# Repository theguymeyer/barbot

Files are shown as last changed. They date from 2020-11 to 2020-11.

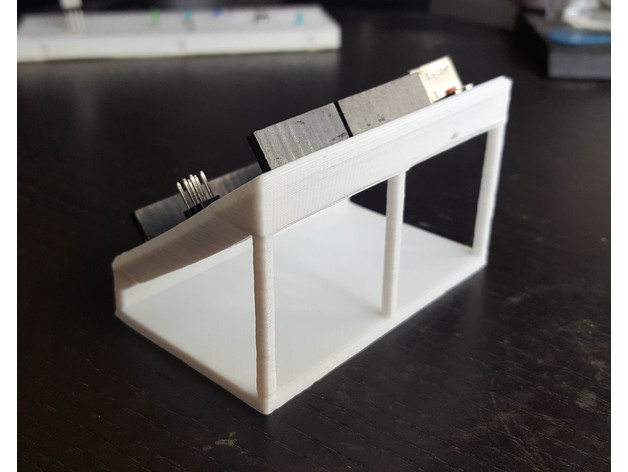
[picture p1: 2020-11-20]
CAD/Arduino_Uno_Breadboard_Stand/images/e8f078489b42e7dd9708c227b31c532c_preview_featured.jpg

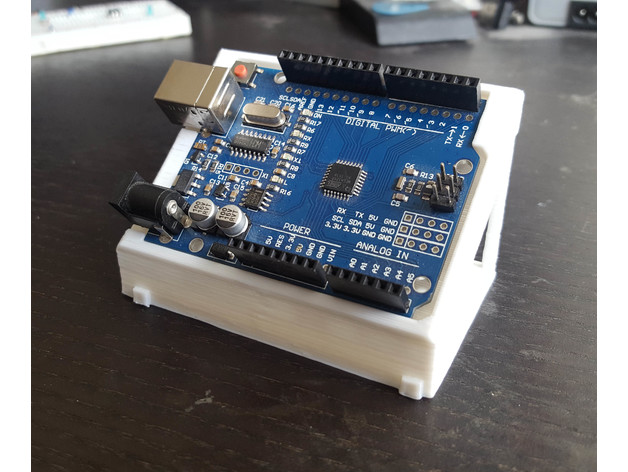
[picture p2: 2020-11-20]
CAD/Arduino_Uno_Breadboard_Stand/images/93188645c2328523fab258e460d34e7b_preview_featured.jpg

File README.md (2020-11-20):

# Bartender Robot

Feelin thirsty? Why dont you spend every summer obsessing over the same project until you get it perfectly... Introducing the Barbot, an autonomous bartender that won't charge you double for a watered down beverage.

But... how? Well this beauty is built on top the finest shelf Ikea has to offer, along with a custom bottle mount this bad boy can hold up to 5 bottles in a line. The main controller (mainFile_rev1) is an Arduino Uno that controls a Bipolar NEMA 17 to move the cup and a set of relays to power the solenoid valve the pneumatics. In order to get enough juice on the pouring action (something that for the life of me, I did not imagine would be so hard) is a 2-stroke pneumatic piston operating under 45 PSI of pressure, controlled by a 2-position 12V Solenoid Valve. The air channels are also equipt with a tunable flow restrictor to provide smooooooooth motion.

Well thats cool but how do I use it? The UI is displayed on an LCD mounted on top another Arduino Uno (yes... the budget was low). The user can scroll between the drink options, select their favourite and watch the bartender go to work.

Just like most of my excessively detailed projects, there are a total of 17 3D printed parts plus other custom elements!

If you enjoyed checking out this project take a look at [my project page](https://guymeyer.me/projects)

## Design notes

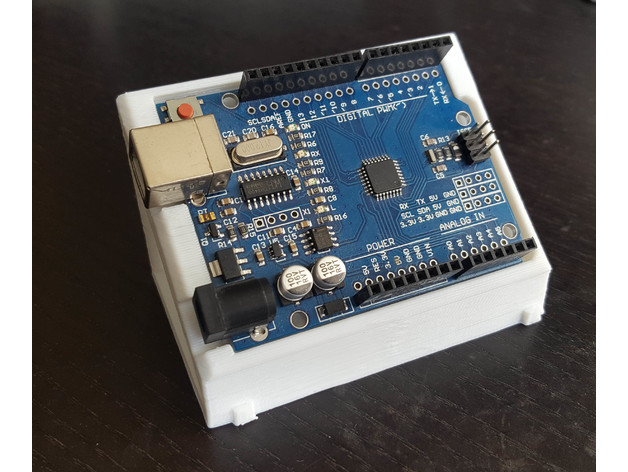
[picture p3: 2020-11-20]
CAD/Arduino_Uno_Breadboard_Stand/images/13b41aad88eadf36f711034ac9c3a466_preview_featured.jpg

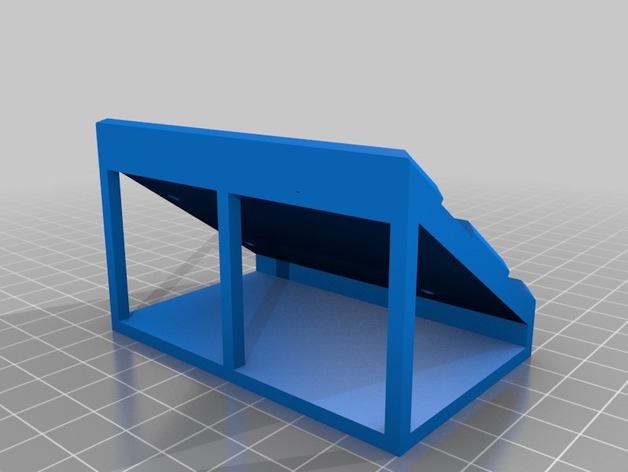
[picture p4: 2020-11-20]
CAD/Arduino_Uno_Breadboard_Stand/images/f9ae25f701ae45b652f5ff1a13d86fba_preview_featured.jpg

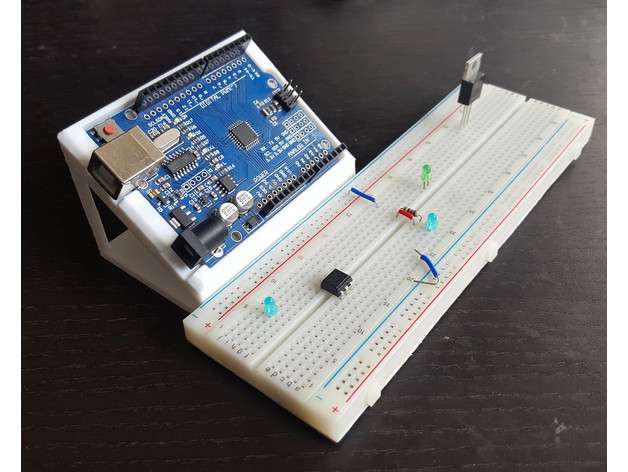
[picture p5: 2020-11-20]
CAD/Arduino_Uno_Breadboard_Stand/images/585fe109f0ed7a9347ead8bb23d2d4b8_preview_featured.jpg

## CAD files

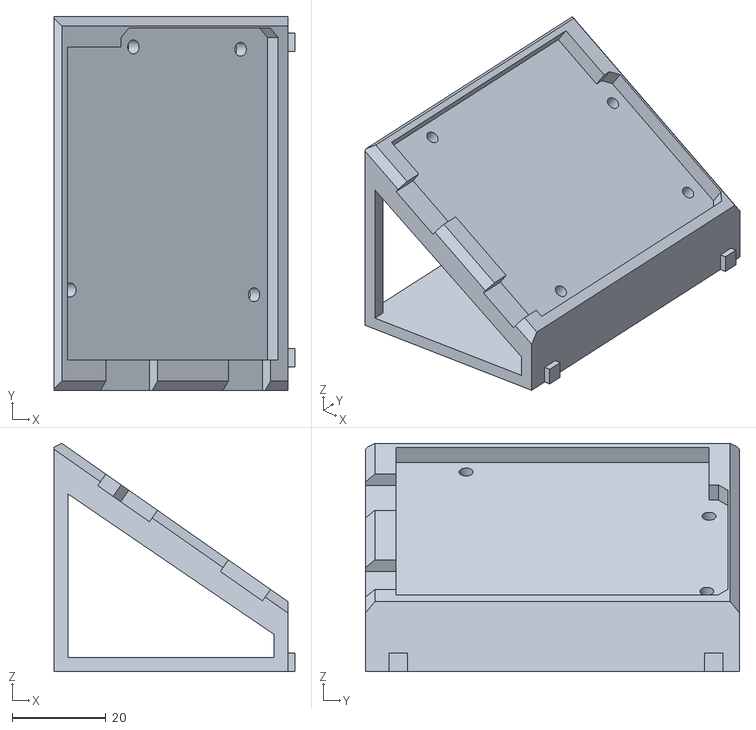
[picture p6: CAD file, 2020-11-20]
CAD/Arduino_Uno_Breadboard_Stand/files/ArduinoUno_Stand.stl
51.5 x 80.0 x 48.9

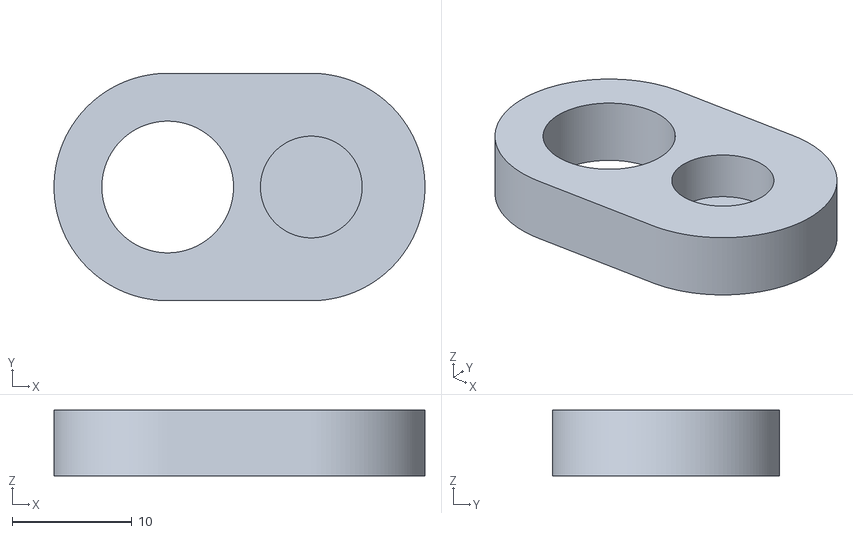
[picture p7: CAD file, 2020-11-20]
CAD/magnet_holder_piston.stl
31.0 x 19.0 x 5.50

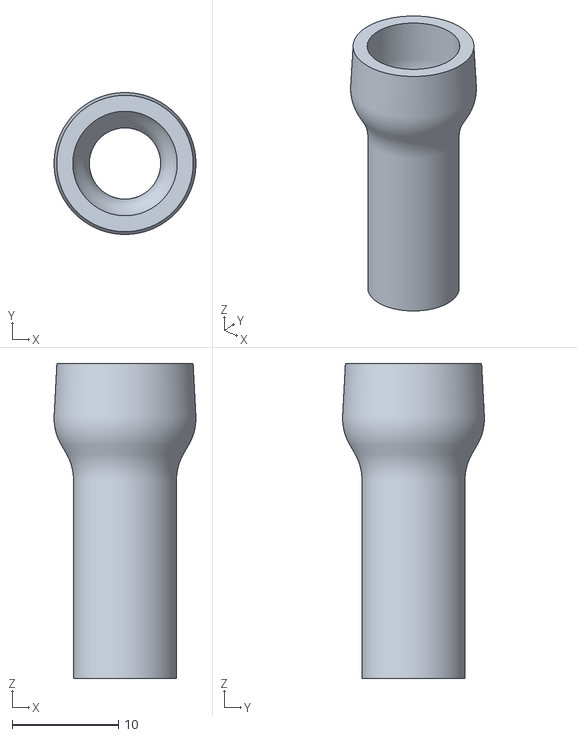
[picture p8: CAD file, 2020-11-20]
CAD/bottle_valve_coupler.stl
13.4 x 13.4 x 29.7

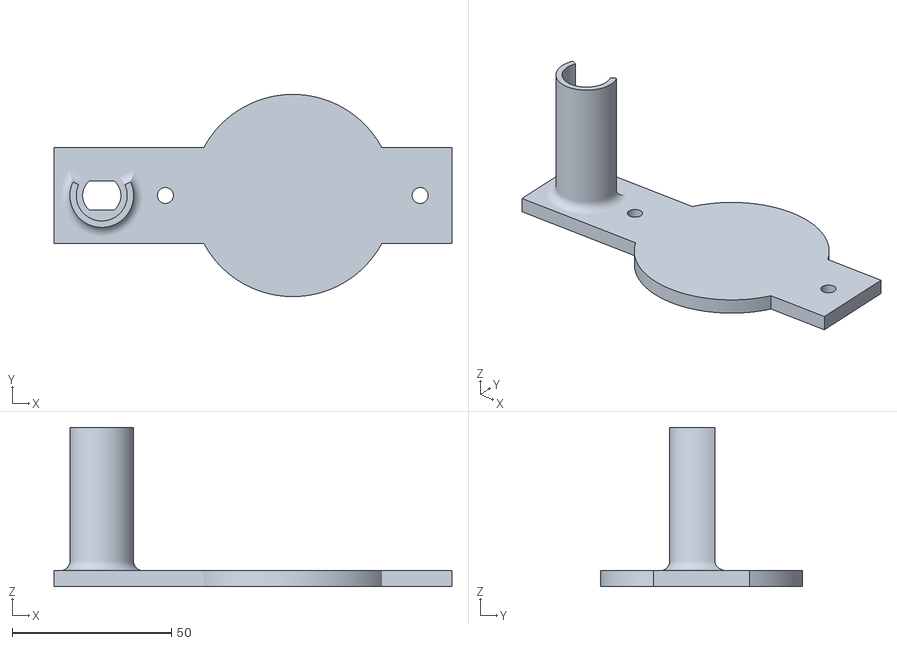
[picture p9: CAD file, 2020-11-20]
CAD/drink_machine_cup_holder.stl
125.0 x 63.5 x 50.0

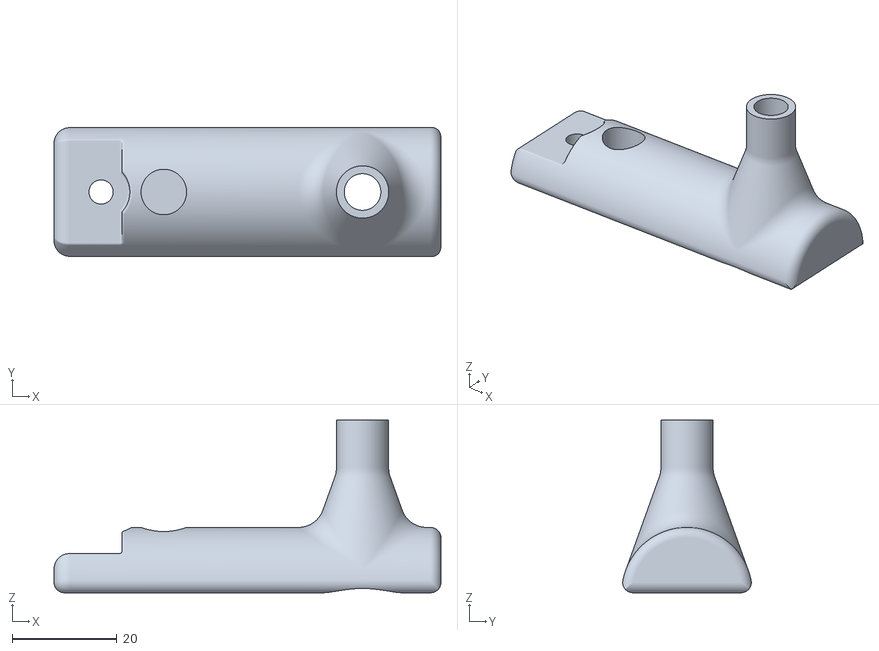
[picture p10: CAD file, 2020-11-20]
CAD/drink_machine_piston_manipulator_rev4.stl
74.0 x 24.6 x 33.0

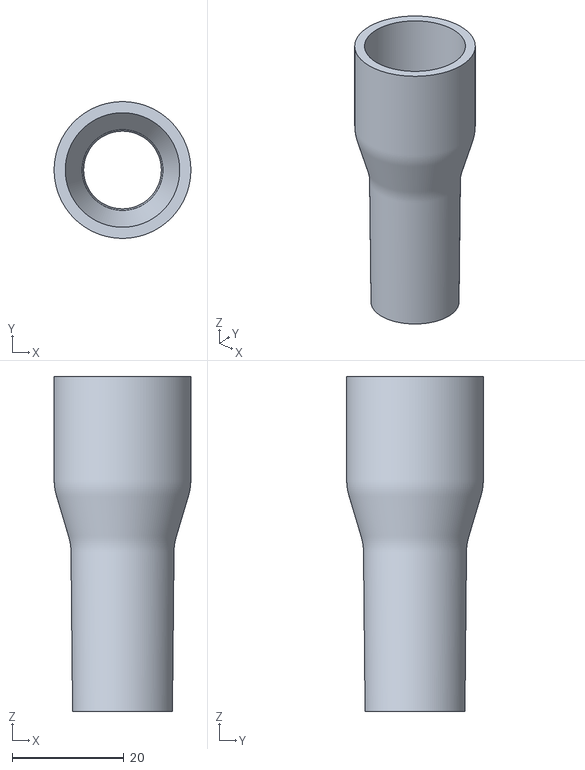
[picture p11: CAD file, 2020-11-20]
CAD/bottle_valve_coupler2.stl
24.5 x 24.5 x 60.0

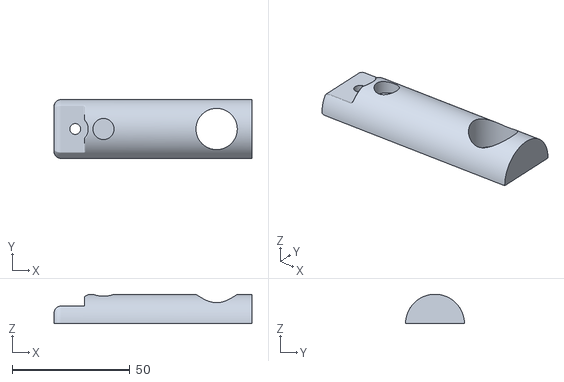
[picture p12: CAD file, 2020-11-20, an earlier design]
CAD/drink_machine_piston_manipulator_rev1.stl
84.0 x 25.0 x 12.5

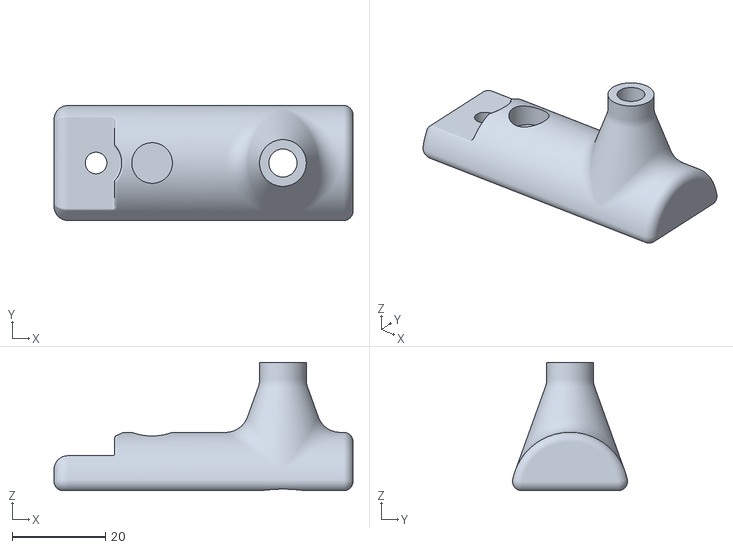
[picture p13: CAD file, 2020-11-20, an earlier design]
CAD/drink_machine_piston_manipulator_rev3.stl
64.0 x 24.6 x 27.5

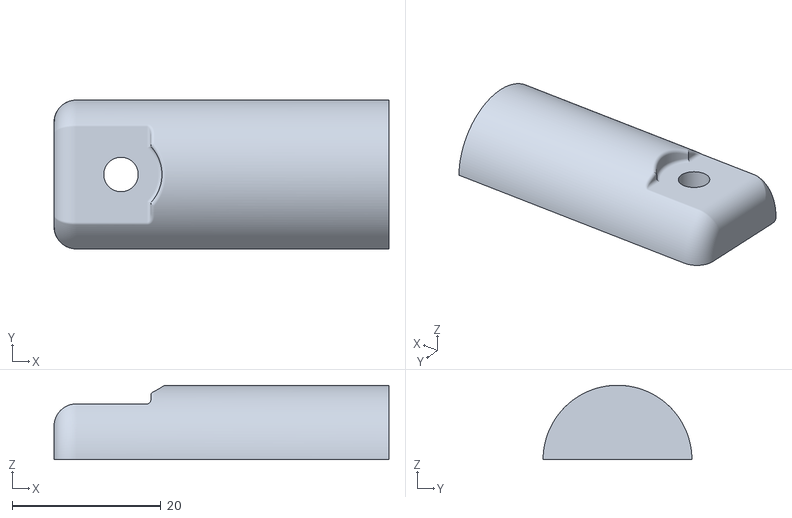
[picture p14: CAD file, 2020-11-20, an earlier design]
CAD/drink_machine_piston_manipulator_rev0.stl
45.0 x 20.0 x 10.0

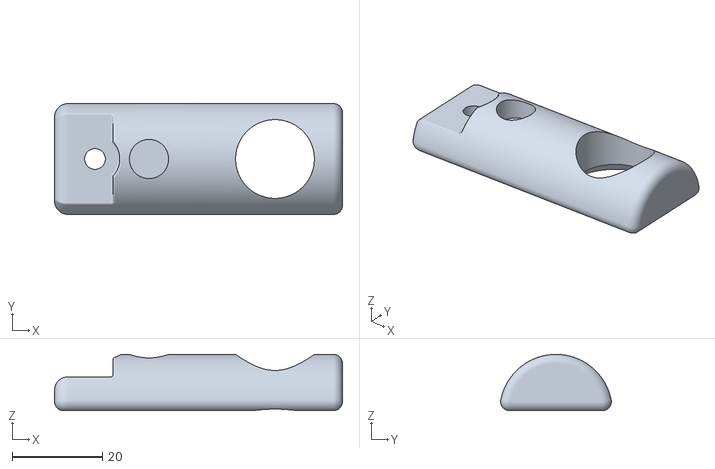
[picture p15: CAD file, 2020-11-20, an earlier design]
CAD/drink_machine_piston_manipulator_rev2.stl
64.0 x 24.6 x 12.5

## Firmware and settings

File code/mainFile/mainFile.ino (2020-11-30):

// Author: Guy Meyer
// Date of creation: May 18th 2020
// Last change date: June 8th 2020
// Objective: accept user input (serial) and execute the drink combination
// System Description:
//	- Hardware: 
//      IR Sensor
//      200 step NEMA 17 Bipolar Stepper providing linear motion underneat bottles
//      12VDC Pneumatic Valve + 2-way piston used to dispense drink + 200 PSI compressor (set to 40 PSI)
//
//	- Electrical: 
//      9VDC stable power. 
//      The RESET button is electrically connected to the power of the board and will perform a hard reset (ie. reinitialization).
//      IR senses proximity and outputs 5V bollean value
//
//	- Software: 
//			INPUT: a serial message indicating the drink requirements based on 5 unique bottle
//			serial message structure: uint8{Bottle_1, Bottle_2, Bottle_3, Bottle_4, Bottle_5} @ BAUDRATE=9600 via RX/TX serial bus
//			where each Bottle is a byte describing the number of shots from each bottle in ASCII. The system is not concerned with speed optimization with the serial buffer
//
//      OUTPUT: 
//      Electrical signals to stepper based on Bottle. 
//      Stops stepper if reached endpoint
//      Toggles solenoid via electrical signals
//      System timing
//      Serial reply when completed
//      `
//
// Design: 
//      On init -> INIT state 
//        - the system will write init_code to serial buffer indicating that its ready to serve
//        - the system will reset its end-effector -> first move piston down, then reset rail to starting position
//      USER_INPUT state
//        - detected new message in serial buffer
//        - Parse serial message to build drink list
//      PATH_PLANNER state
//        - Build a plan for the stepper's motion
//      MAKE_DRINK state
//        LOOP: move to bottle -> pour shot (x number of shots) -> if more bottle repeat, else break
//      SERVE_DRINK state
//        - the system will reset its end-effector -> first move piston down, then reset rail to starting position
//        - the system will send finished drink code to UI
//
//         /                                     /                                  /
//      _\/_______                            _\/__________                      _\/____________                   _______________                   _______________  
//  o-->|  INIT   |          -->              | USER_INPUT |       -->           | PATH_PLANNER |       -->        |  MAKE_DRINK  |       -->        | SERVE_DRINK |
//      |_________|  SERIAL INIT DETECTED     |____________|   PARSED MESSAGE    |______________|  DEFINED PLAN    |______________|  EXECUTED PATH   |_____________|
//                                                /\                                                                                                       |
//                                                 |_______________________________________________________________________________________________________|
//                                                                                                SERIAL DETECTED (new drink)
//
//
//

#include <Adafruit_MotorShield.h>
#include <Vector.h>

#define DRINK_COUNT 5
#define IR_THRESHOLD 0.9

#define BOTTLE1_POS 500   // in number fo steps from start
#define BOTTLE2_POS 1500
#define BOTTLE3_POS 2500
#define BOTTLE4_POS 3500
#define BOTTLE5_POS 4500
#define RAIL_MAX 5500

// TESTING
//#define BOTTLE1_POS 100   // in number fo steps from start
//#define BOTTLE2_POS 200
//#define BOTTLE3_POS 300
//#define BOTTLE4_POS 400
//#define BOTTLE5_POS 500
//#define RAIL_MAX 1000

#define DRINK_HOLD_TIME 3000
#define DRINK_INBETWEEN_TIME 2500

//using namespace std;

// init variables
int LimitSW_Pin = 2;    // connected to digital 2
int pistonUp_Pin = 6;   // pneumatic controls
int pistonDown_Pin = 7;
int bottle_position [5] = {BOTTLE1_POS, BOTTLE2_POS, BOTTLE3_POS, BOTTLE4_POS, BOTTLE5_POS};

Adafruit_MotorShield AFMS = Adafruit_MotorShield(); 
Adafruit_StepperMotor *myMotor = AFMS.getStepper(200, 1);


// state variables
int pmsg [DRINK_COUNT] = {0};  // parsed message
int path [DRINK_COUNT][2] = {0}; // servo path
int stop_count = 0;

/* --- Custom Functions --- */

// alters the solenoid values to move the piston DOWN
bool pistonDown()
{
  digitalWrite(pistonUp_Pin, LOW);
  digitalWrite(pistonDown_Pin, HIGH);
}

// alters the solenoid values to move the piston UP
bool pistonUp()
{
  digitalWrite(pistonDown_Pin, LOW);
  digitalWrite(pistonUp_Pin, HIGH);
}

// moves the drink closer to the IR (starting position) with incremental steps
// -> return true on successful motion (returns false otherwise)
bool resetRail()
{
  pistonDown(); 
  delay(2000);
  
  while(!(isStepperAtStart())) {
    myMotor->step(10, FORWARD, DOUBLE);  // move closer
    delay(2); // give the motor time to move
  }

  // reached start
  pistonUp();
  return true;

}

bool isStepperAtStart()
{
  
  if (digitalRead(LimitSW_Pin)) {
    return true;
  }

  return false;
}

/* --- State Functions (executed on entry unless otherwise noted) --- */

// system init - runs on boot
// -> returns true when serial is established and the rail is reset (returns false otherwise)
bool init_sys()
{

  String ACK;
  if (Serial.available()) {
    ACK = Serial.readString();  // ACK receive

    if (ACK == "OK\n") {  // transition criteria

      resetRail();

      Serial.flush();
      Serial.flush();
      return true;
    }
  }

  return false;

}

// a waiting state for serial input regarding drink info
// updates the message buffer from serial stream (requirements for each drink) starting from closest
void userInput(int msg_buffer[])
{

  String message = Serial.readString();

  if (message != NULL) {  // if message in buffer
    for (int i = 0; i < DRINK_COUNT; i++) {
      msg_buffer[i] = message[i] - '0';
    }
  }

  // clean up
  Serial.flush();
  Serial.flush();

}

// Takes the user input and builds a path for the servo as a list of steps with directions
// returns a list of instructions for the stepper (2d vector) [direction, steps, shots]
// direction defined as 0 - FORWARD (closer to start), 1 - BACKWARD (away from start) 
// RETURNS the number of stops (ie. number of different requested drinks, the volume of each does not matter)
int pathPlanner(int msg_buffer[], int path_buffer[][2])
{
  // Note this function can be later optimized for better path planning
  
//  while (!isStepperAtStart()) { resetRail(); }

  int instruction [2] = {0,0};
  int path_index = 0;
  for (int d = 0; d < DRINK_COUNT; d++) {

    if (msg_buffer[d] != 0) {
      path_buffer[path_index][0] = bottle_position[d];
      path_buffer[path_index][1] = msg_buffer[d];
      path_index ++;
    }

  }

  return path_index;

}

// Execution of path - moves cup through positions and pours liquor
// Assumption: only requested liquors are in the path buffer
void exec(int path_buf[][2], int stop_count)
{

  resetRail();
  pistonDown();
  delay(1000);

  int loc = 50;
  uint8_t dir;
  
  myMotor->step(loc, BACKWARD, DOUBLE);

  for (int i = 0; i < stop_count; i++) {

    // move stepper to position until within margin of error - 10 steps
    while (abs(path_buf[i][0] - loc) > 1) {
      
      if (isStepperAtStart() || loc > RAIL_MAX) { 
        pistonDown();
        resetRail();
        return ; 
      }
      
      if (path_buf[i][0] > loc) {
        myMotor->step(1, BACKWARD, DOUBLE);
        loc++;
      } else {
        myMotor->step(1, FORWARD, DOUBLE);
        loc--;
      }

//      delay(2); // give the motor time to move
    }

    for (int j = 0; j < path_buf[i][1]; j++) {

      delay(DRINK_INBETWEEN_TIME);
      pistonUp();
      delay(DRINK_HOLD_TIME);
      pistonDown();
      delay(DRINK_INBETWEEN_TIME);

    }

    
    delay(300);

  }

  // return home
  resetRail();
  delay(100);
  myMotor->release();
  
}

void setup() 
{ 
  Serial.begin(9600); // init serial - no direct imports

  while (!Serial)
  {
    ; // wait for serial port to connect. Needed for native USB port only
  }

  AFMS.begin();  // create with the default frequency 1.6KHz
  myMotor->setSpeed(1000);  // 10 rpm 
  
  pinMode(LimitSW_Pin, INPUT);
  pinMode(pistonUp_Pin, OUTPUT);
  pinMode(pistonDown_Pin, OUTPUT);

//  myMotor->step(10, BACKWARD, DOUBLE);
  //myMotor->release();

  while ( !(init_sys()) ) {}  // run init until it works and system is ready to go (return true)
  
} 

void loop() 
{

  // wait for new input
  if (Serial.available()) {
    userInput(pmsg);
    
    // path planner
    stop_count = pathPlanner(pmsg, path);
    
    // exec (move servo and actuate piston)
    exec(path, stop_count);
    
    // return home

    Serial.print("DONE");
    delay(1000);
    Serial.flush();
    Serial.flush();

  }

  // wait for new input
  delay(50);

  
  //Serial.println("thinking");

}

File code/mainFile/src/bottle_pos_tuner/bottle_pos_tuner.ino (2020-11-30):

// Author: Guy Meyer
// Date: Nov 29 2020
// Objective: Use this file to accurately locate the position of the bottles


#include <Adafruit_MotorShield.h>

#define BOTTLE1_POS 500   // in number fo steps from start
#define BOTTLE2_POS 1500
#define BOTTLE3_POS 2500
#define BOTTLE4_POS 3500
#define BOTTLE5_POS 4500
#define RAIL_MAX 5500

int bottle_position [5] = {BOTTLE1_POS, BOTTLE2_POS, BOTTLE3_POS, BOTTLE4_POS, BOTTLE5_POS};
int location = 0;
int steps;
int LimitSW_Pin = 2; //connected to digital 
int pistonUp_Pin = 6;   // pneumatic controls
int pistonDown_Pin = 7;
String data;

Adafruit_MotorShield AFMS = Adafruit_MotorShield(); 
Adafruit_StepperMotor *myMotor = AFMS.getStepper(200, 1);

// moves the drink closer to the IR (starting position) with incremental steps
// -> return true on successful motion (returns false otherwise)
bool resetRail()
{
  
  while(!(isStepperAtStart())) {
    myMotor->step(10, FORWARD, DOUBLE);  // move closer
    delay(2); // give the motor time to move
  }

  // reached start
  return true;

}

bool isStepperAtStart()
{
  
  if (digitalRead(LimitSW_Pin)) {
    return true;
  }

  return false;
}

// alters the solenoid values to move the piston DOWN
bool pistonDown()
{
  digitalWrite(pistonUp_Pin, LOW);
  digitalWrite(pistonDown_Pin, HIGH);
}

// alters the solenoid values to move the piston UP
bool pistonUp()
{
  digitalWrite(pistonDown_Pin, LOW);
  digitalWrite(pistonUp_Pin, HIGH);
}

void softRelease()
{
//  digitalWrite(pistonDown_Pin, HIGH);
  digitalWrite(pistonDown_Pin, HIGH);

  delay(5);
  pistonUp();
  
}


void setup() {
  Serial.begin(9600); // init serial - no direct imports

  while (!Serial)
  {
    ; // wait for serial port to connect. Needed for native USB port only
  }

  AFMS.begin();  // create with the default frequency 1.6KHz
  //AFMS.begin(1000);  // OR with a different frequency, say 1KHz
  
  myMotor->setSpeed(3000);  // 10 rpm 
  pinMode( LimitSW_Pin, INPUT );
  pinMode(pistonUp_Pin, OUTPUT);
  pinMode(pistonDown_Pin, OUTPUT);
  resetRail();

}

void loop() {
  

  if (Serial.available()) {

    data = Serial.readString();

    if (data == "r") { resetRail(); location = 0;}
    else if (data == "u") { pistonUp(); }
    else if (data == "d") { pistonDown(); }
    else if (data == "s") { softRelease(); }
    else {
      steps = data.toInt();
      location = location + steps;
      
      myMotor->step(steps, BACKWARD, DOUBLE);
    }

    Serial.print("The Current position is: ");
    Serial.println(location);
    myMotor->release();
  }
}

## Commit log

2020-03-11 speeding up stepper and new CAD for piston manipulator
    [drink_machine_piston_manipulator_rev4.stl]
2020-11-20 add adafruit motorshield
2020-11-29 working reset button
2020-11-30 adding pistons
